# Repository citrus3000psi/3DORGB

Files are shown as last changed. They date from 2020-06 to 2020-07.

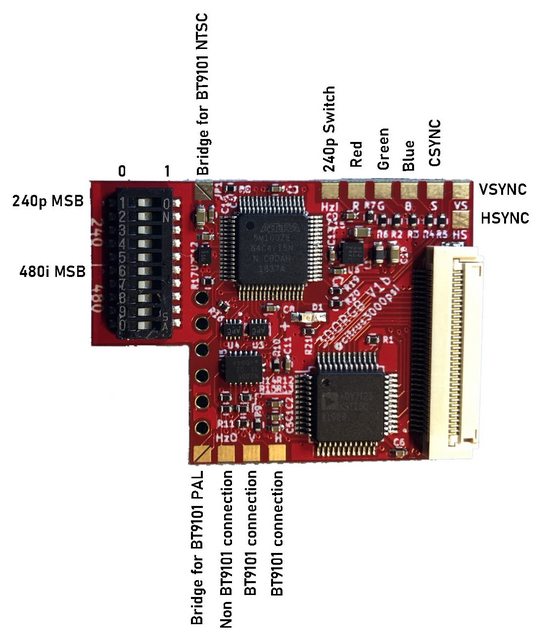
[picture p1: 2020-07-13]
MainBoard/Kicad/FR4/8hDpdkwl.jpg

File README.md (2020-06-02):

# 3DORGB
RGB Project for most 3DO consoles.

Copyright 2020 Daniel Kunz

Permission is hereby granted, free of charge, to any person obtaining a copy of this software and associated documentation files (the "Software"), to deal in the Software without restriction, including without limitation the rights to use, copy, modify, merge, publish, distribute, sublicense, and/or sell copies of the Software, and to permit persons to whom the Software is furnished to do so, subject to the following conditions:

The above copyright notice and this permission notice shall be included in all copies or substantial portions of the Software.

THE SOFTWARE IS PROVIDED "AS IS", WITHOUT WARRANTY OF ANY KIND, EXPRESS OR IMPLIED, INCLUDING BUT NOT LIMITED TO THE WARRANTIES OF MERCHANTABILITY, FITNESS FOR A PARTICULAR PURPOSE AND NONINFRINGEMENT. IN NO EVENT SHALL THE AUTHORS OR COPYRIGHT HOLDERS BE LIABLE FOR ANY CLAIM, DAMAGES OR OTHER LIABILITY, WHETHER IN AN ACTION OF CONTRACT, TORT OR OTHERWISE, ARISING FROM, OUT OF OR IN CONNECTION WITH THE SOFTWARE OR THE USE OR OTHER DEALINGS IN THE SOFTWARE.

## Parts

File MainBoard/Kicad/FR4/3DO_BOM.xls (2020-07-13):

Reference | Quantity | Value | Footprint | Notes
C1 C11 C12 C13 C2 C3 C4 C5 C6 C7 C8 C9 | 12 | .1u | Capacitors_SMD:C_0402 | 16V or higher
C10 C14 C15 | 3 | 10u | Capacitors_SMD:C_0603 | 16V or higher
J1 | 1 | 3-1775333-2 | 3-1775333-2:TE_3-1775333-2
L1 | 1 | ACML-0603-110-TCT-ND | Capacitors_SMD:C_0603
R1 | 1 | 523 | Resistors_SMD:R_0402 | 1%
R10 | 1 | 200K | Resistors_SMD:R_0402
R2 R3 R4 | 3 | 75 | Resistors_SMD:R_0402
R16 R7 R21 | 3 | 1K | Resistors_SMD:R_0402
R17 R6 R8 | 4 | 10K | Resistors_SMD:R_0402
R11 R12 R13 R14 R15 R9 | 6 | 523 | Resistors_SMD:R_0402
U1 | 1 | ADV7125KSTZ50 | Housings_QFP:TQFP-48_7x7mm_Pitch0.5mm
U2 | 1 | 5M160ZE64I5N | QFP40P900X900X120-65N:QFP40P900X900X120-65N
U3 U4 | 2 | 7WB383MUTAG | SON40P180X120X55-8N:SON40P180X120X55-8N
U5 | 1 | NVT2006BQ,115 | QFN50P250X350X100-17N:QFN50P250X350X100-17N
U6 | 1 | TPS73733DRVR | digikey-footprints:UDFN-6-1EP_2x2mm
U7 | 1 | MIC94310-GYMT-TR | pads:MIC94310
D1 | 1 | 150060BS75000 | Capacitors_SMD:C_0603 | Blue LED
R19 R20 | 1 | 47 | Resistors_SMD:R_0402
R5 | 1 | 510 | Resistors_SMD:R_0402
SW1 | 1 | CHS-10TA | SW10 DIP 1.27mm

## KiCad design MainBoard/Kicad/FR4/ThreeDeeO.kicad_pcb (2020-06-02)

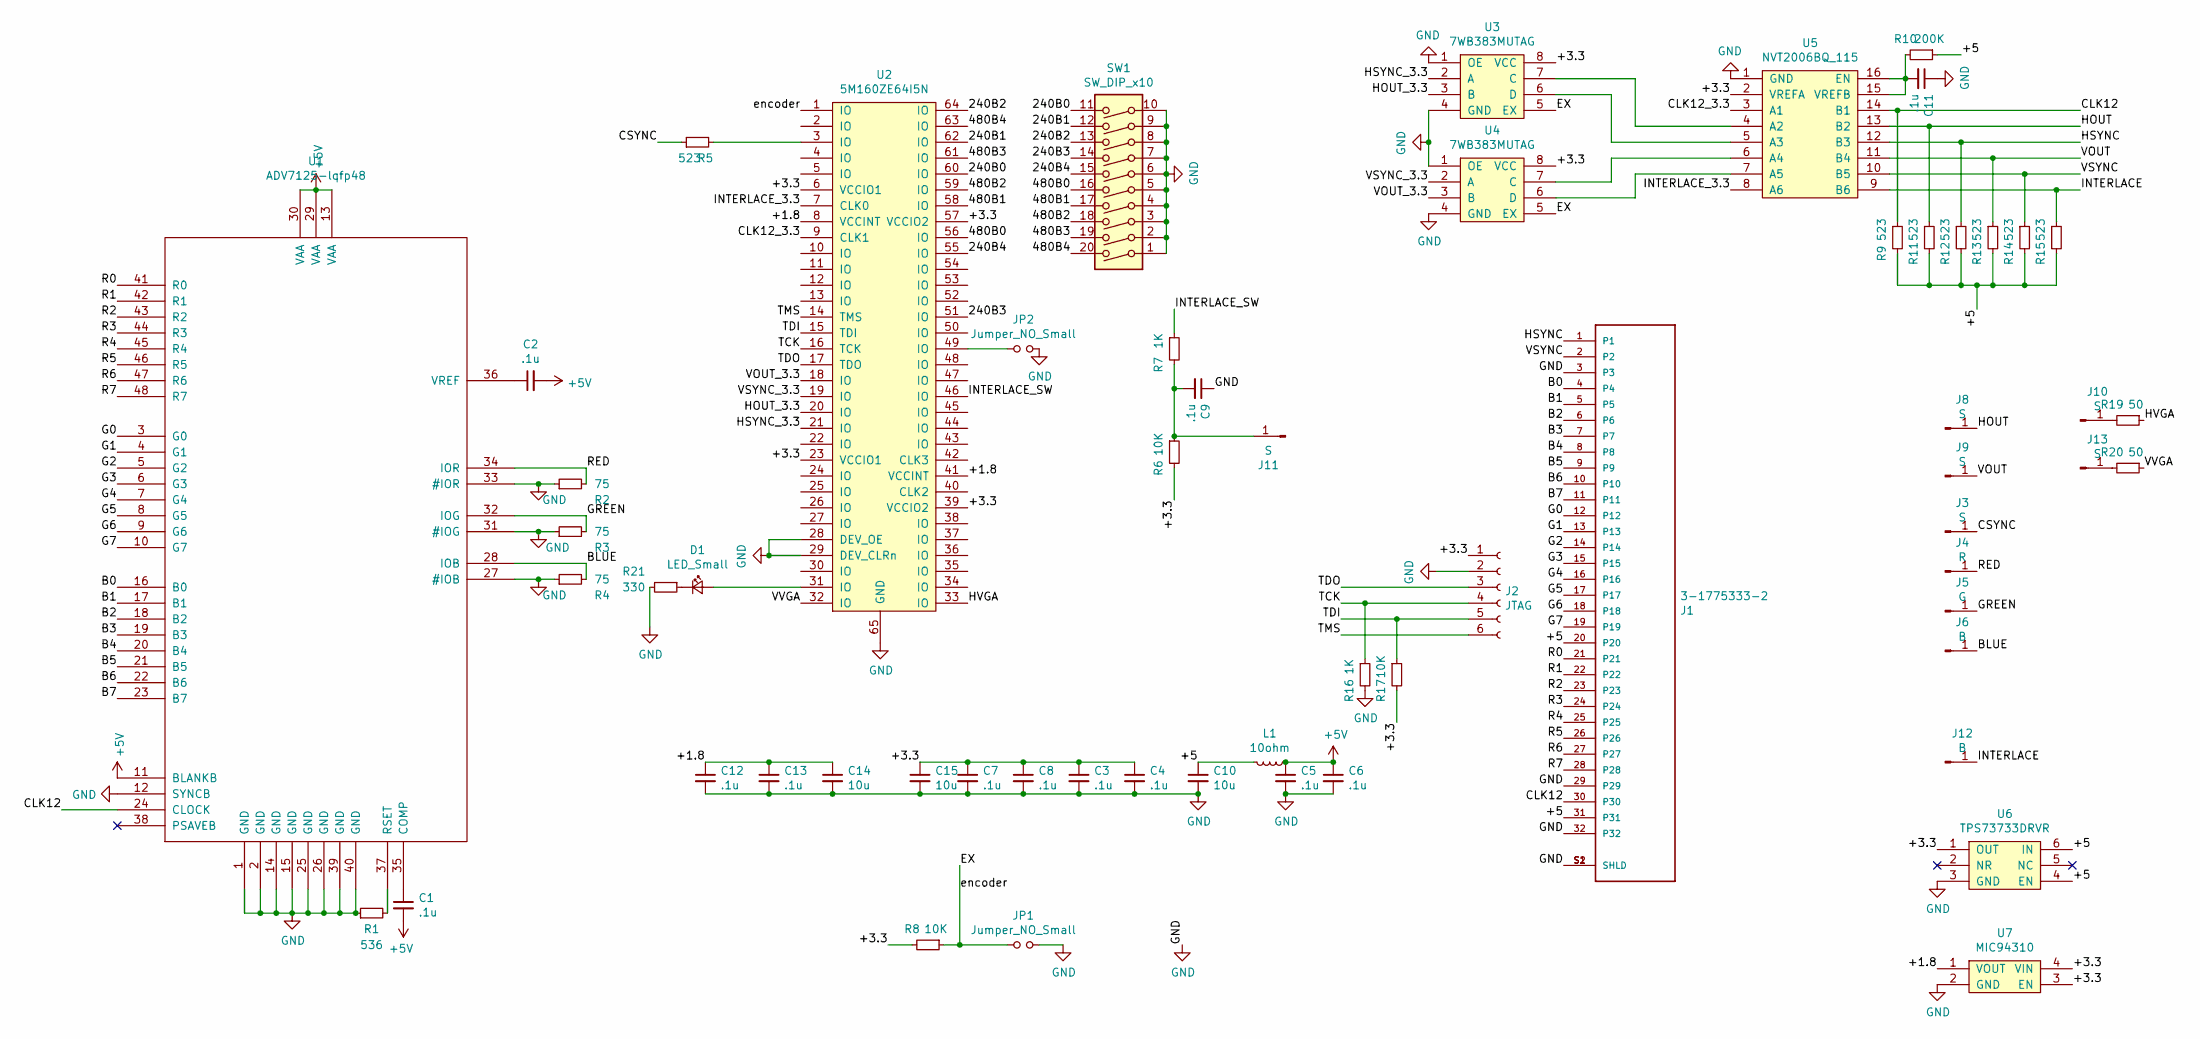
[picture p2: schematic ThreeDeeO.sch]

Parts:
C1, C2, C3, C4, C5, C6, C7, C8, C9, C11, C12, C13: .1u; C_0402
C10, C14, C15: 10u; C_0603
D1: LED_Small; LED_0603_HandSoldering
J1: 3-1775333-2; TE_3-1775333-2
J2: JTAG; SPI_PADS
J3, J8, J9, J10, J11, J13: S; small_pad
J4: R; small_pad
J5: G; small_pad
J6, J12: B; small_pad
JP1, JP2: Jumper_NO_Small; Jumper
L1: 10ohm; C_0603
R1: 536; R_0402
R2, R3, R4: 75; R_0402
R5, R9, R11, R12, R13, R14, R15: 523; R_0402
R6, R8, R17: 10K; R_0402
R7, R16: 1K; R_0402
R10: 200K; R_0402
R19, R20: 50; R_0402
R21: 330; R_0402
SW1: SW_DIP_x10; SWDIP10
U1: ADV7125-lqfp48; TQFP-48_7x7mm_Pitch0.5mm
U2: 5M160ZE64I5N; QFP40P900X900X120-65N
U3, U4: 7WB383MUTAG; SON40P180X120X55-8N
U5: NVT2006BQ_115; QFN50P250X350X100-17N
U6: TPS73733DRVR; UDFN-6-1EP_2x2mm
U7: MIC94310

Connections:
+5V: C1.2, C2.2, C5.1, C6.1, L1.1, U1.11 (BLANKB), U1.13 (VAA), U1.29 (VAA), U1.30 (VAA)
/240B0: SW1.11, U2.60 (IO)
/240B1: SW1.12, U2.62 (IO)
/240B2: SW1.13, U2.64 (IO)
/240B3: SW1.14, U2.51 (IO)
/240B4: SW1.15, U2.55 (IO)
/480B0: SW1.16, U2.56 (IO)
/480B1: SW1.17, U2.58 (IO)
/480B2: SW1.18, U2.59 (IO)
/480B3: SW1.19, U2.61 (IO)
/480B4: SW1.20, U2.63 (IO)
/+1.8: C12.1, C13.1, C14.1, U2.8 (VCCINT), U2.41 (VCCINT), U7.1 (VOUT)
/+3.3: C3.1, C4.1, C7.1, C8.1, C15.1, J2.1, R6.2, R8.2, R17.2, U2.6 (VCCIO1), U2.23 (VCCIO1), U2.39 (VCCIO2), U2.57 (VCCIO2), U3.8 (VCC), U4.8 (VCC), U5.2 (VREFA), U6.1 (OUT), U7.3 (EN), U7.4 (VIN)
/+5: C10.1, J1.20, J1.31, L1.2, R9.2, R10.1, R11.2, R12.2, R13.2, R14.2, R15.2, U6.4 (EN), U6.6 (IN)
/B0: J1.4, U1.16 (B0)
/B1: J1.5, U1.17 (B1)
/B2: J1.6, U1.18 (B2)
/B3: J1.7, U1.19 (B3)
/B4: J1.8, U1.20 (B4)
/B5: J1.9, U1.21 (B5)
/B6: J1.10, U1.22 (B6)
/B7: J1.11, U1.23 (B7)
/BLUE: J6.1, R4.2, U1.28 (IOB)
/CLK12: J1.30, R9.1, U1.24 (CLOCK), U5.14 (B1)
/CLK12_3.3: U2.9 (CLK1), U5.3 (A1)
/CSYNC: J3.1, R5.1
/EX: JP1.1, R8.1, U2.1 (IO), U3.5 (EX), U4.5 (EX)
/G0: J1.12, U1.3 (G0)
/G1: J1.13, U1.4 (G1)
/G2: J1.14, U1.5 (G2)
/G3: J1.15, U1.6 (G3)
/G4: J1.16, U1.7 (G4)
/G5: J1.17, U1.8 (G5)
/G6: J1.18, U1.9 (G6)
/G7: J1.19, U1.10 (G7)
/GREEN: J5.1, R3.2, U1.32 (IOG)
/HOUT: J8.1, R11.1, U5.13 (B2)
/HOUT_3.3: U2.20 (IO), U3.3 (B)
/HSYNC: J1.1, R12.1, U5.12 (B3)
/HSYNC_3.3: U2.21 (IO), U3.2 (A)
/HVGA: R19.1, U2.33 (IO)
/INTERLACE: J12.1, R15.1, U5.9 (B6)
/INTERLACE_3.3: U2.7 (CLK0), U5.8 (A6)
/INTERLACE_SW: R7.1, U2.46 (IO)
/R0: J1.21, U1.41 (R0)
/R1: J1.22, U1.42 (R1)
/R2: J1.23, U1.43 (R2)
/R3: J1.24, U1.44 (R3)
/R4: J1.25, U1.45 (R4)
/R5: J1.26, U1.46 (R5)
/R6: J1.27, U1.47 (R6)
/R7: J1.28, U1.48 (R7)
/RED: J4.1, R2.2, U1.34 (IOR)
/TCK: J2.4, R16.1, U2.16 (TCK)
/TDI: J2.5, R17.1, U2.15 (TDI)
/TDO: J2.3, U2.17 (TDO)
/TMS: J2.6, U2.14 (TMS)
/VOUT: J9.1, R13.1, U5.11 (B4)
/VOUT_3.3: U2.18 (IO), U4.3 (B)
/VSYNC: J1.2, R14.1, U5.10 (B5)
/VSYNC_3.3: U2.19 (IO), U4.2 (A)
/VVGA: R20.1, U2.32 (IO)
GND: C3.2, C4.2, C5.2, C6.2, C7.2, C8.2, C9.1, C10.2, C11.1, C12.2, C13.2, C14.2, C15.2, J1.3, J1.29, J1.32, J1.S1 (SHLD), J1.S2 (SHLD), J2.2, JP1.2, JP2.2, R1.1, R2.1, R3.1, R4.1, R16.2, R21.2, SW1.1, SW1.2, SW1.3, SW1.4, SW1.5, SW1.6, SW1.7, SW1.8, SW1.9, SW1.10, U1.1 (GND), U1.2 (GND), U1.12 (SYNCB), U1.14 (GND), U1.15 (GND), U1.25 (GND), U1.26 (GND), U1.27 (#IOB), U1.31 (#IOG), U1.33 (#IOR), U1.39 (GND), U1.40 (GND), U2.28 (DEV_OE), U2.29 (DEV_CLRn), U2.65 (GND), U3.1 (OE), U3.4 (GND), U4.1 (OE), U4.4 (GND), U5.1 (GND), U6.3 (GND), U7.2 (GND)
unnamed: C1.1, U1.35 (COMP)
unnamed: C2.1, U1.36 (VREF)
unnamed: C9.2, J11.1, R6.1, R7.2
unnamed: C11.2, R10.2, U5.15 (VREFB), U5.16 (EN)
unnamed: D1.1 (K), R21.1
unnamed: D1.2 (A), U2.31 (IO)
unnamed: J10.1, R19.2
unnamed: J13.1, R20.2
unnamed: JP2.1, U2.49 (IO)
unnamed: R1.2, U1.37 (RSET)
unnamed: R5.2, U2.3 (IO)
unnamed: U3.6 (D), U5.5 (A3)
unnamed: U3.7 (C), U5.4 (A2)
unnamed: U4.6 (D), U5.7 (A5)
unnamed: U4.7 (C), U5.6 (A4)

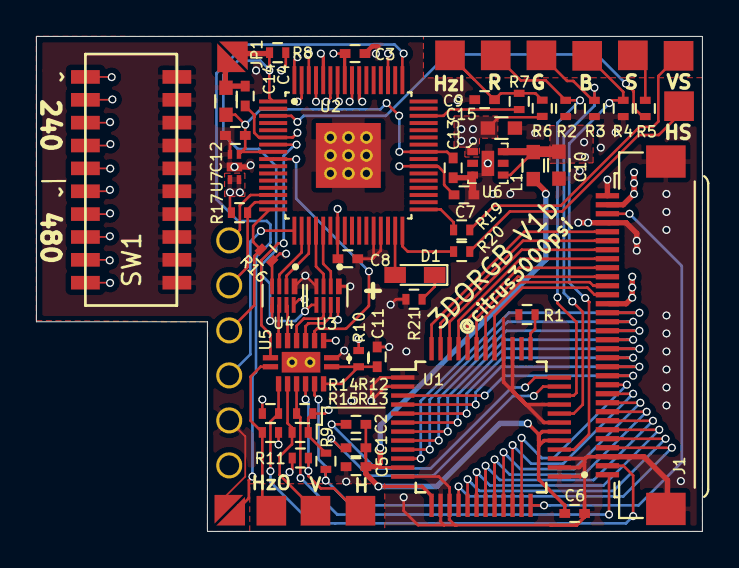
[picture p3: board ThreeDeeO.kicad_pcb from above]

Board: 4 copper layers, 37.0 x 27.5 mm, 59 parts (0 on the bottom side), 78 nets.

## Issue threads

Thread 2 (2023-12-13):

MiniDin and Breakout pcbs gerbers Edge cuts

rapiqui, 2023-12-13:
Hi,

I wanted to give a try to your great design and ordered pcbs for every board on this project.
I found out that the already created and published gerbers were not processed correctly by a PCB provider.
This was not a problem for the main board and flex, as Kicad project is shared and I could recreate the gerbers according to the PCB provider requirements and those appear now correctly.

Unfortunately this is not the case with the breakout/spacer and miniDin PCBs.
¿Could you please add the Kicad project of those or recreate the gerbers with this specs:

Layers:
F.Cu
F.Paste
F.Silks
F.Mask
B.Cu
B.Paste
B.Silks
B.Mask
Edge.Cuts
In1.Cu, In2.Cu

General Options:

Plot reference designators
Check zone fills before plotting

Gerber Options:

Use Protel File Extensions
Substract soldermask from silkscreen

Thank you.

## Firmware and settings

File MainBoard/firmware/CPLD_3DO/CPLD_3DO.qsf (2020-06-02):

# -------------------------------------------------------------------------- #
#
# Copyright (C) 2017  Intel Corporation. All rights reserved.
# Your use of Intel Corporation's design tools, logic functions 
# and other software and tools, and its AMPP partner logic 
# functions, and any output files from any of the foregoing 
# (including device programming or simulation files), and any 
# associated documentation or information are expressly subject 
# to the terms and conditions of the Intel Program License 
# Subscription Agreement, the Intel Quartus Prime License Agreement,
# the Intel FPGA IP License Agreement, or other applicable license
# agreement, including, without limitation, that your use is for
# the sole purpose of programming logic devices manufactured by
# Intel and sold by Intel or its authorized distributors.  Please
# refer to the applicable agreement for further details.
#
# -------------------------------------------------------------------------- #
#
# Quartus Prime
# Version 17.1.0 Build 590 10/25/2017 SJ Lite Edition
# Date created = 14:16:42  August 07, 2019
#
# -------------------------------------------------------------------------- #
#
# Notes:
#
# 1) The default values for assignments are stored in the file:
#		CPLD_3DO_assignment_defaults.qdf
#    If this file doesn't exist, see file:
#		assignment_defaults.qdf
#
# 2) Altera recommends that you do not modify this file. This
#    file is updated automatically by the Quartus Prime software
#    and any changes you make may be lost or overwritten.
#
# -------------------------------------------------------------------------- #


set_global_assignment -name FAMILY "MAX V"
set_global_assignment -name DEVICE 5M160ZE64I5
set_global_assignment -name TOP_LEVEL_ENTITY CPLD_3DO
set_global_assignment -name ORIGINAL_QUARTUS_VERSION 17.1.0
set_global_assignment -name PROJECT_CREATION_TIME_DATE "14:16:42  AUGUST 07, 2019"
set_global_assignment -name LAST_QUARTUS_VERSION "17.1.0 Lite Edition"
set_global_assignment -name PROJECT_OUTPUT_DIRECTORY output_files
set_global_assignment -name MIN_CORE_JUNCTION_TEMP "-40"
set_global_assignment -name MAX_CORE_JUNCTION_TEMP 125
set_global_assignment -name ERROR_CHECK_FREQUENCY_DIVISOR "-1"
set_global_assignment -name VERILOG_FILE CPLD_3DO.v
set_global_assignment -name POWER_PRESET_COOLING_SOLUTION "NO HEAT SINK WITH STILL AIR"
set_global_assignment -name OPTIMIZATION_MODE "AGGRESSIVE PERFORMANCE"
set_global_assignment -name TIMEQUEST_MULTICORNER_ANALYSIS OFF
set_global_assignment -name NUM_PARALLEL_PROCESSORS ALL
set_global_assignment -name FIT_ATTEMPTS_TO_SKIP 0
set_global_assignment -name OPTIMIZE_POWER_DURING_FITTING "NORMAL COMPILATION"
set_global_assignment -name AUTO_PACKED_REGISTERS_MAX "MINIMIZE AREA WITH CHAINS"
set_global_assignment -name OPTIMIZE_TIMING "NORMAL COMPILATION"
set_global_assignment -name ROUTER_EFFORT_MULTIPLIER 2.0
set_global_assignment -name PHYSICAL_SYNTHESIS_EFFORT EXTRA
set_global_assignment -name MUX_RESTRUCTURE OFF
set_location_assignment PIN_9 -to clk12
set_location_assignment PIN_3 -to csync_o
set_location_assignment PIN_1 -to encoder
set_location_assignment PIN_21 -to hsync
set_location_assignment PIN_20 -to hsync_o
set_location_assignment PIN_46 -to interlace_in
set_location_assignment PIN_7 -to interlace_out
set_location_assignment PIN_19 -to vsync
set_location_assignment PIN_18 -to vsync_o
set_location_assignment PIN_33 -to hsync_o_VGA
set_location_assignment PIN_32 -to vsync_o_VGA
set_location_assignment PIN_31 -to led
set_location_assignment PIN_49 -to encoder_bt9103
set_instance_assignment -name WEAK_PULL_UP_RESISTOR ON -to encoder_bt9103
set_instance_assignment -name IO_STANDARD "3.3-V LVTTL" -to b0_240
set_location_assignment PIN_60 -to b0_240
set_location_assignment PIN_56 -to b0_480
set_location_assignment PIN_62 -to b1_240
set_location_assignment PIN_58 -to b1_480
set_location_assignment PIN_64 -to b2_240
set_location_assignment PIN_59 -to b2_480
set_location_assignment PIN_51 -to b3_240
set_location_assignment PIN_61 -to b3_480
set_location_assignment PIN_55 -to b4_240
set_location_assignment PIN_63 -to b4_480
set_instance_assignment -name WEAK_PULL_UP_RESISTOR ON -to b0_240
set_instance_assignment -name WEAK_PULL_UP_RESISTOR ON -to b0_480
set_instance_assignment -name WEAK_PULL_UP_RESISTOR ON -to b1_240
set_instance_assignment -name WEAK_PULL_UP_RESISTOR ON -to b1_480
set_instance_assignment -name WEAK_PULL_UP_RESISTOR ON -to b2_240
set_instance_assignment -name WEAK_PULL_UP_RESISTOR ON -to b2_480
set_instance_assignment -name WEAK_PULL_UP_RESISTOR ON -to b3_240
set_instance_assignment -name WEAK_PULL_UP_RESISTOR ON -to b3_480
set_instance_assignment -name WEAK_PULL_UP_RESISTOR ON -to b4_240
set_instance_assignment -name WEAK_PULL_UP_RESISTOR ON -to b4_480

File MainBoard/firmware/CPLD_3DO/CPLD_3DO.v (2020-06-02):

module CPLD_3DO(
    
	 input b0_240,
	 input b1_240,
	 input b2_240,
	 input b3_240,
	 input b4_240,
	 input b0_480,
	 input b1_480,
	 input b2_480,
	 input b3_480,
	 input b4_480,
	 input       clk12,
    input       hsync,
    input       vsync,
    input       interlace_in,
    //encoder choice, BT9101=0 others=1
    input       encoder,
	 //encoder choice, BT9101PAL=0 others=1
	 input		 encoder_bt9103,
    output reg  interlace_out,
    output wire hsync_o,
	 output wire led,
    output wire vsync_o,
    output wire csync_o,
	 output wire hsync_o_VGA,
    output wire vsync_o_VGA
);
    reg vsync2 = 0;
    reg hsync2 = 0;  
	 reg hsync3 = 0;
    reg prev_vsync = 0;
    reg prev_hsync = 0;
    reg [9:0] h_count = 0;
    reg [9:0] new_h_count = 0;
    reg [9:0] h_total = 0;
    reg [7:0] h_low_count = 0;
    reg hsync_mod = 1'b1;
    reg [4:0] shift_value = 0;
    reg [11:0] CounterX = 0;
    reg [8:0] CounterY = 0;
	 reg [8:0] counterled = 0;
	 reg LED_status = 0;
	 reg var_b0_240;
	 reg var_b1_240;
	 reg var_b2_240;
	 reg var_b3_240;
	 reg var_b4_240;
	 reg var_b0_480;
	 reg var_b1_480;
	 reg var_b2_480;
	 reg var_b3_480;
	 reg var_b4_480;
	 reg interlace_startup=0;
	 reg startup_buf=0;
	 reg vsync_start=0;
	 
    localparam GENERATED_240P_WIDTH = 796;
    localparam GENERATED_240P_HEIGHT = 262;
    localparam GENERATED_240P_HEIGHT_PAL = 288;
    localparam HSYNC_SHIFT_240P_MOD = 5'b00000;
    localparam HSYNC_SHIFT_480I_MOD = 5'b11000;
	 localparam VSYNC_SHIFT_LENGTH = 10'b1001110001;
 	 localparam VSYNC_SHIFT_LENGTHBT = 12'b100101100000;

	 always @(negedge clk12) begin
		  
	 var_b0_240 <= !b0_240;
	 var_b1_240 <= !b1_240;
	 var_b2_240 <= !b2_240;
	 var_b3_240 <= !b3_240;
	 var_b4_240 <= !b4_240;
	 var_b0_480 <= !b0_480;
	 var_b1_480 <= !b1_480;
	 var_b2_480 <= !b2_480;
	 var_b3_480 <= !b3_480;
	 var_b4_480 <= !b4_480;
    prev_vsync <= vsync2;
    prev_hsync <= hsync2;

	 
	 
 	if(!startup_buf) begin
		interlace_startup<=interlace_in;
		startup_buf<=1;
	end 
	 
        // skip first frame before activating interlace_out
        if (prev_vsync != vsync2 && prev_hsync != hsync2 && !vsync2) begin
				interlace_out <= interlace_in;
         
				
				
				if(!encoder || !encoder_bt9103) begin
					shift_value <= interlace_in ? {var_b0_240, var_b1_240 , var_b2_240 , var_b3_240 , var_b4_240} : {var_b0_480 , var_b1_480 , var_b2_480 , var_b3_480 , var_b4_480};				
				end else begin
					shift_value <= interlace_startup ? {var_b0_240, var_b1_240 , var_b2_240 , var_b3_240 , var_b4_240} : {var_b0_480 , var_b1_480 , var_b2_480 , var_b3_480 , var_b4_480};			
				end
			
				
				counterled <= counterled + 1'b1;
				if (counterled > 119) begin
					LED_status <= !LED_status;
					counterled <= 7'b0;
				end
		  end

        // hysnc buffers and counters 
        if ((prev_hsync != hsync2) && !hsync2) begin
            h_count <= 0;
            new_h_count <= 0;
            h_total <= h_count - shift_value;  // make hsync trigger earlier
        end else begin
            h_count <= h_count + 1'b1;
            new_h_count <= new_h_count + 1'b1; 
        end

        // generate hsync for csync output
        if (new_h_count == h_total) begin
            hsync_mod <= 0;
            h_low_count <= 0;
        end else begin
            if (h_low_count == 6'b111100) begin  // make hsync low pulse longer
					 hsync_mod <= 1'b1;
            end else begin
                h_low_count <= h_low_count+1;  
            end
        end

        
		  // BT9101 Encoder 240p - generate timings
       

        if ((!encoder || !encoder_bt9103) && interlace_in) begin
						
				
				  	// BT9101 MODE - Output 240P signal, ignore syncs from DAC
						if (CounterX < GENERATED_240P_WIDTH - 1) begin
								CounterX <= CounterX + 1;
						end else begin
								CounterX <= 0;
								if (CounterY < (encoder_bt9103 ?	GENERATED_240P_HEIGHT : GENERATED_240P_HEIGHT_PAL) - 1) begin
									CounterY <= CounterY + 1;
								end else begin
									CounterY <= 0;
								end
						end
						
					
						
						vsync2 <= ~(CounterY <= 3);
						hsync2 <= ~(CounterX[9:6] == 0);
						hsync3 <= hsync_mod;
				
						  
		  end else begin
					
					if(!vsync && !vsync_start) begin
					 CounterX <= 0;
					 vsync2 <= 0;
					 vsync_start<=1;
					end else if(CounterX < VSYNC_SHIFT_LENGTHBT)begin
						CounterX <= CounterX + 1;
					end else begin
						vsync_start <= 0;
						vsync2 <= 1;
					end
				
			
			
					hsync2 <= hsync;
					//pass shifted_hsync for VGA output
					hsync3 <= hsync_mod;	
		  end
    end
	 
	 
	 assign led=LED_status;
	 assign hsync_o_VGA = hsync3;
    assign vsync_o_VGA = vsync2;    
	 assign hsync_o = hsync3;
    assign vsync_o = vsync2;    
    assign csync_o = (hsync_mod ^ vsync2) ^ 1;
 endmodule

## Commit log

2020-06-02 Files added
    [3DO_BOM.xls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]
2020-07-02 Add MiniDin
    [3DO_BOM.xls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]
2020-07-02 Update Gerber
    [RGBMount-B_Cu.gbl, RGBMount-B_Mask.gbs, RGBMount-Edge_Cuts.gm1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]
2020-07-02 Add breakout
    [MiniDin8Adapter-B_Cu.gbl, MiniDin8Adapter-B_Mask.gbs, MiniDin8Adapter-B_SilkS.gbo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]
2020-07-08 Added correct BOM
    [3DO_BOM.xls]
2020-07-08 Minor updates
    [3DO_BOM.xls, ThreeDeeO.sch]
2020-07-08 Correct BOM
    [3DO_BOM.xls]
2020-07-08 Use tested gerbers from last run
    [ThreeDeeO-B_Cu.gbl, ThreeDeeO-B_Mask.gbs, ThreeDeeO-B_SilkS.gbo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]
2020-07-13 Removed R18 which is no longer in use
    [3DO_BOM.xls]
2020-10-16 Added 9pin gerbers
    [MiniDin8Adapter-B_Cu.gbl, MiniDin8Adapter-B_Mask.gbs, MiniDin8Adapter-B_SilkS.gbo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]
